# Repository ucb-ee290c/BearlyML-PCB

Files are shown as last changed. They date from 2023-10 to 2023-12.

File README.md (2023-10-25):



# BearlyML-PCB

This is the PCB for BearlyML 22 SoC chip, designed by EE 194/290C students in Spring 2022. 

## Functional Description

The design consists of two boards. The Module Board breaks out the chip BGA signals to the SODIMM connector. The Carrier Board contains most of the IO modules and level shifters. The Carrier Board can be swapped to different designs for different bringup setups or demo applications.

## Project Links

[BearlyML 2022 SoC Specification](https://docs.google.com/document/d/1Ldz2ZDB1uXTN-R59TmTNYh7_aXbSfiJJrKeP0uHo0qY/edit?usp=sharing)

[BearlyML 2022 Testing Note](https://docs.google.com/presentation/d/11BuBN2AjHtR5hc7lh9h7Z0UspvnxgiJxumvH6YZSuuI/edit?usp=sharing)

[PCB Design Review Slides](https://docs.google.com/presentation/d/1bnDwFzTTJ-bXILV92_7TXTGvEWACcQbSM0IduBUi0zo/edit?usp=sharing)

[PCB Project on GitHub](https://github.com/ucb-ee290c/BearlyML-PCB)

[PCB Project on Altium 365 - Module](https://ucb-bar.365.altium.com/designs/3D97ECBB-57EB-4ED6-8AAA-B185523FADBC#design)

[PCB Project on Altium 365 - Carrier](https://ucb-bar.365.altium.com/designs/955C9C27-6A6A-45D4-90F7-2286846251A1#design)

[PCB Project in BWRC-Boards](https://bwrcrepo.eecs.berkeley.edu/pcb/BearlyML-PCB)

## Schematic

[View on Altium 365](https://ucb-bar.365.altium.com/designs/3D97ECBB-57EB-4ED6-8AAA-B185523FADBC#design)

[Schematic PDF - Module](BearlyML_Module_Board/schematic-pdf/Schematic_BearlyML%20Module%20Board_2022-12-21.pdf)

[Schematic PDF - Carrier](BearlyML_Carrier_Board/schematic-pdf/Schematic_BearlyML%20Carrier%20Board_2022-12-21.pdf)

### Manufacture

[JLCPCB](https://jlcpcb.com/capabilities/Capabilities)

### Parameters

| Key | Value |
| ---- | --- |
| Build Time | 5-6 days |
| Layers | 6  |
| PCB Qty | 5 |
| PCB Thickness | 1.2 mm for Module Board; 1.6 mm for Carrier Board |
| Base Material | FR-4 |
| Material Type | FR4-Standard TG 135-140 |
| Dimension | 79.6 mm* 71 mm for Module Board; 100 mm* 92 mm for Carrier Board |
| Product Type | Industrial/Consumer electronics |
| Impedance Control | no |
| Silkscreen | White |
| PCB Color | Black |
| Surface Finish | ENIG Gold Thickness: 1 U" |
| Via Covering | Epoxy Filled & Capped |
| Via Type | via-in-pad |
| Outer Copper Weight | 1 oz |
| Inner Copper Weight | 0.5 oz |
| Castellated Holes | no |
| Min hole size/diameter | 0.2/0.45mm |
| Flying Probe Test | Fully Test |
| Gold Fingers | Yes for Module Board |
| Remove Order Number | Specify a location |
| Appearance Quality | IPC Class 2 Standard |
| Silkscreen Technology | Ink-jet/Screen Printing Silkscreen |



Manufactured with [JLCPCB](https://jlcpcb.com/).

## Manufacture Cost

### Module Board

PCB: $18.58 each

Assembly: $17.64 each excluding BOM part cost

### Carrier Board

PCB: $17.81 each

Assembly: $21.90 each excluding BOM part cost

### Total

Total: $380 for 5 pcs

## 3D View

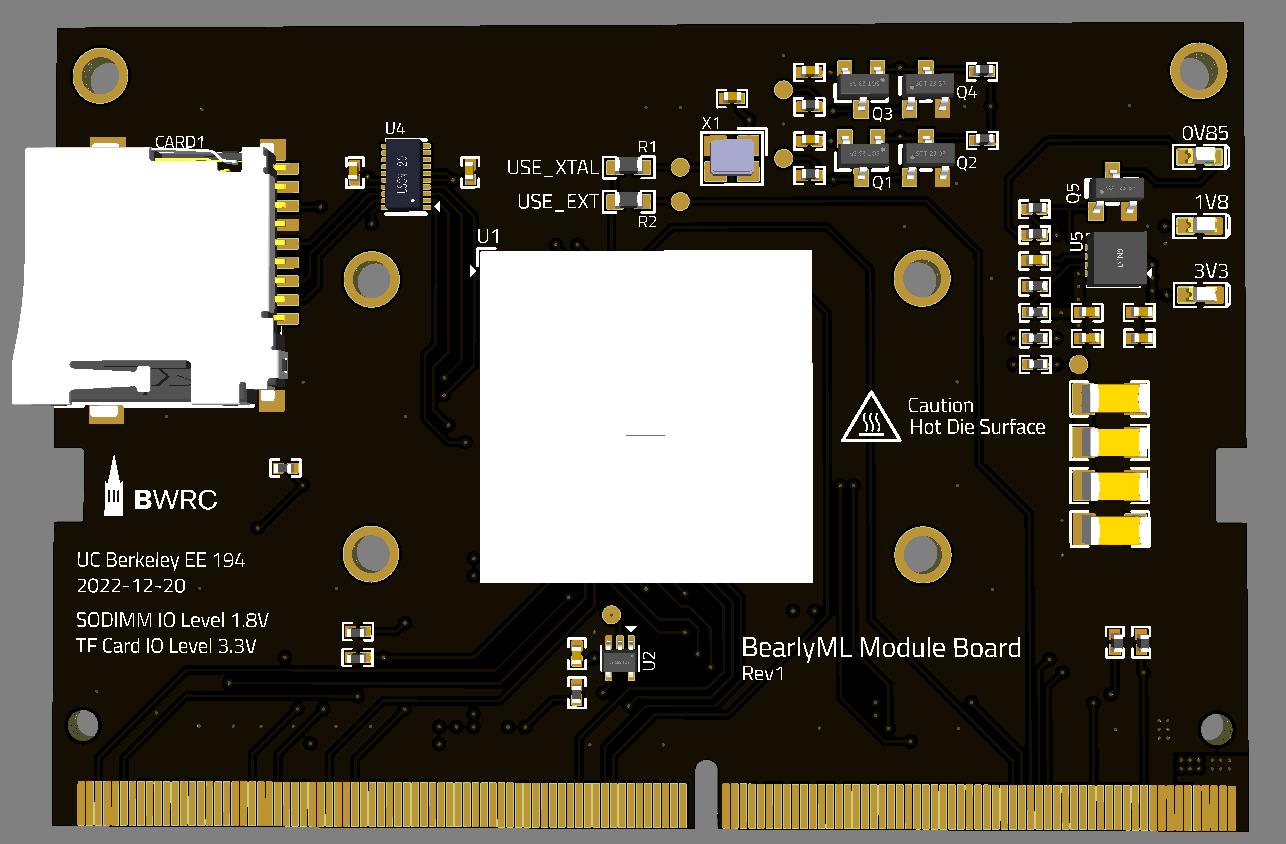
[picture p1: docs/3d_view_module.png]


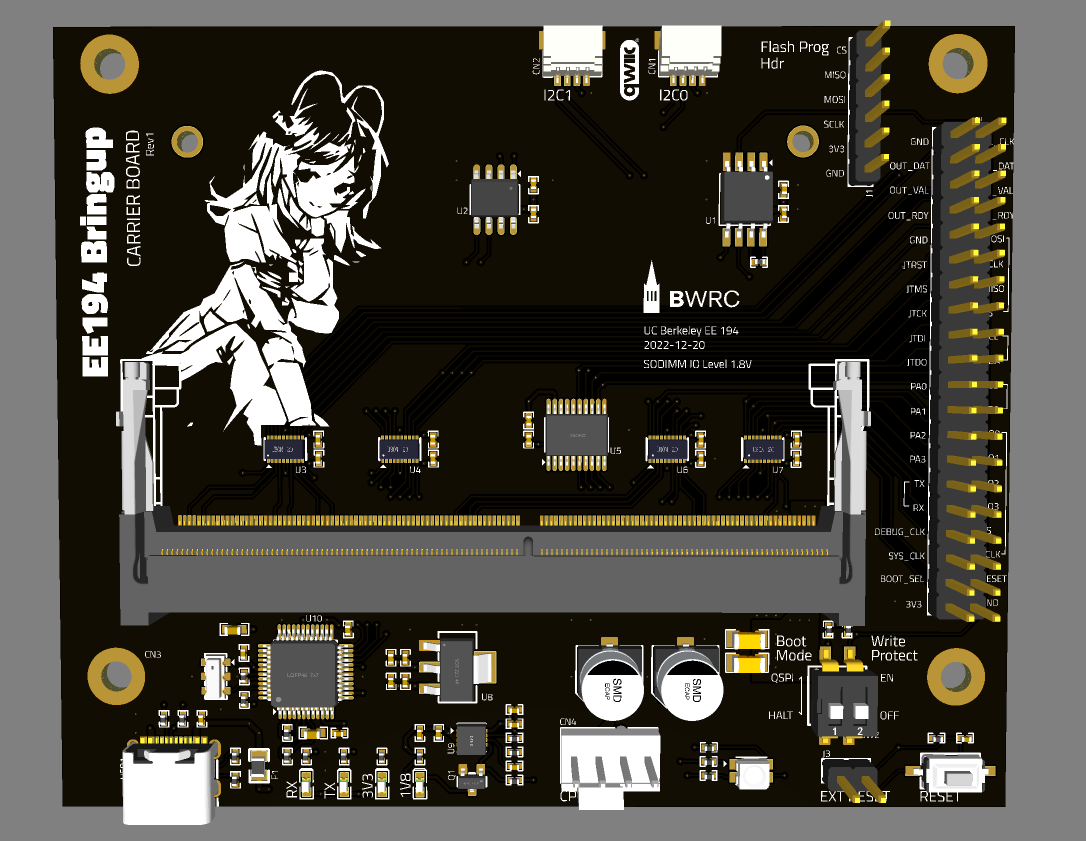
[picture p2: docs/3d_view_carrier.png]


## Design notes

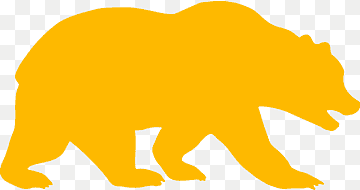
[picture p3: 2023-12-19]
assets/bearlyml_bear.png

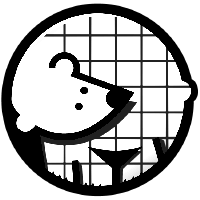
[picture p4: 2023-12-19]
assets/ucb-bar.png

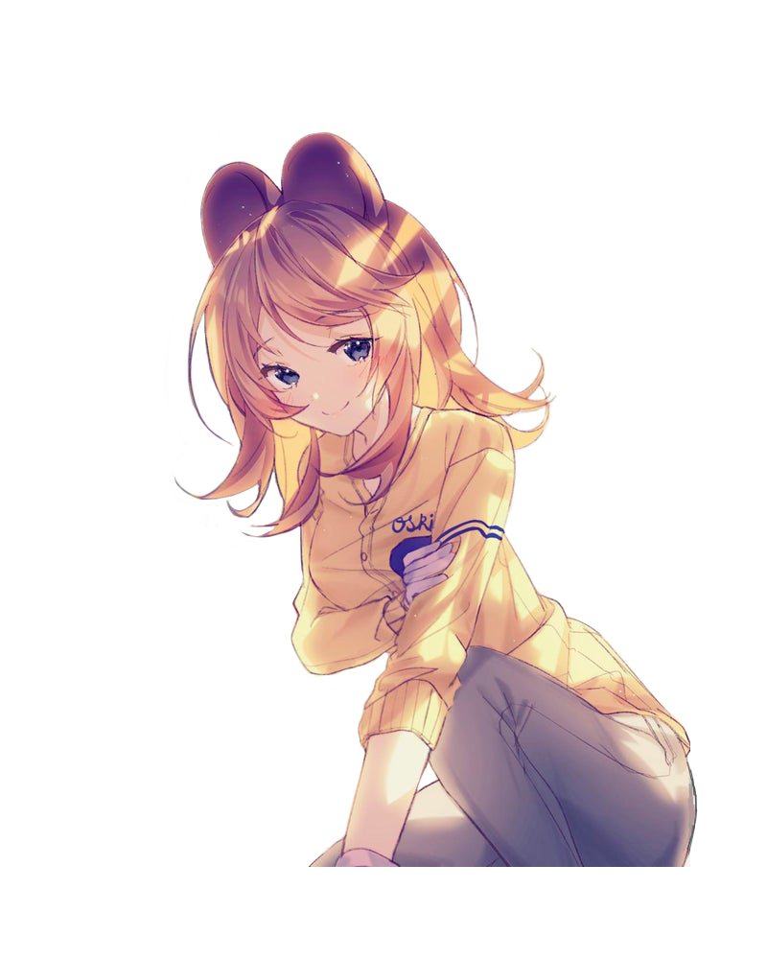
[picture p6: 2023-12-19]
assets/bearlyml_raw.jpg

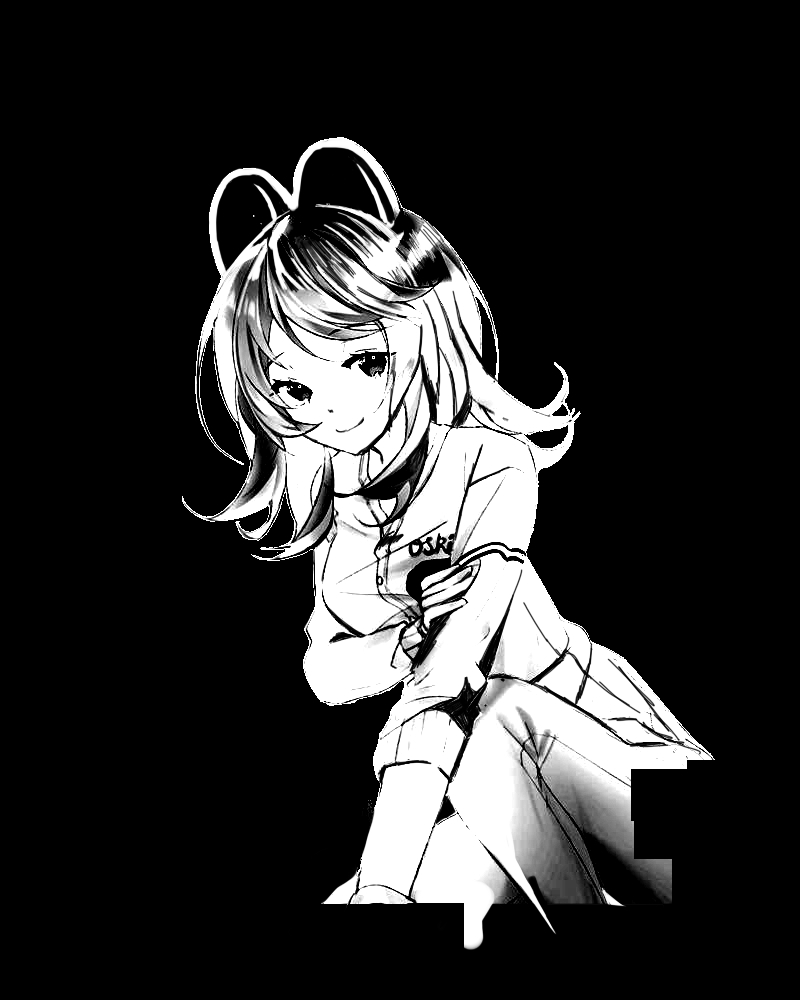
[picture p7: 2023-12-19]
assets/bearlyml.jpg

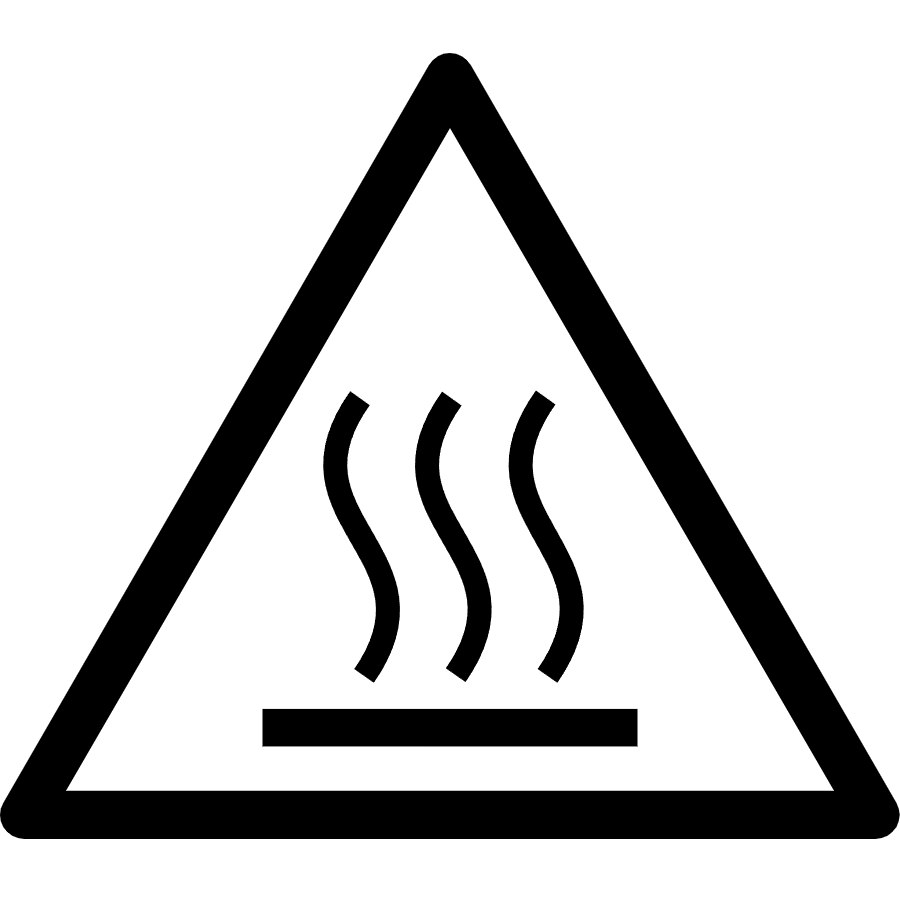
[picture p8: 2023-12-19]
assets/hot.png

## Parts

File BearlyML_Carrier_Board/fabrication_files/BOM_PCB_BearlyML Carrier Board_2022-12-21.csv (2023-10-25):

ID | Name | Designator | Footprint | Quantity | Manufacturer Part | Manufacturer | Supplier | Supplier Part | Price
1 | ASAA826-E8SB0-7H | CN3 | CONN-SMD_ASAA826-E8SB0-7H | 1 | ASAA826-E8SB0-7H | FOXCONN(富士康) | LCSC | C2761395 | 8.05
2 | USB-TYPEC | USB1 | USB-C-SMD_KH-TYPE-C-16P | 1 | KH-TYPE-C-16P | Shenzhen Kinghelm Elec | LCSC | C709357 | 0.5111
3 | KF1027B-02P-L00-ON-01B | SW2 | SW-SMD_4P-L6.1-W6.2-P2.54-LS10.0 | 1 | KF1027B-02P-L00-ON-01B | 凯峰 | LCSC | C976353 | 1.8078
4 | TS-1007S-AR02516 | SW1 | SW-SMD_L6.1-W3.6-LS7.9 | 1 | TS-1007S-AR02516 | XUNPU | LCSC | C720381 | 0.2704
5 | 27R | R7,R9 | RES-0402 | 2 | RCT0227RJLF | HKR | LCSC | C174257 | 0.0093
6 | FDV301N | Q1 | SOT-23_L2.9-W1.3-P1.90-LS2.4-BR | 1 | FDV301N | onsemi(安森美) | LCSC | C15310 | 0.383
7 | 6V 2A | F1 | R0805 | 1 | SL0805200 | TECHFUSE | LCSC | C70158 | 0.3669
8 | AMS1117-3.3 | U8 | SOT-223_L6.5_W3.5_P2.30_BL | 1 | AMS1117-3.3 | Advanced Monolithic Systems | LCSC | C6186 | 0.9139
9 | 1k5 | R27 | RES-0402 | 1 | 0402WGF1501TCE | UniOhm 台湾厚声 | LCSC | C25867 | 0.0026
10 | 10k | R26,R23,R4,R3,R2,R1 | RES-0402 | 6 | 0402WGF1002TCE | UniOhm 台湾厚声 | LCSC | C25744 | 0.0036
11 | 470R | R25 | RES-0402 | 1 | 0402WGF4700TCE | UniOhm 台湾厚声 | LCSC | C25117 | 0.0029
12 | 1M | R24 | RES-0402 | 1 | 0402WGF1004TCE | UniOhm 台湾厚声 | LCSC | C26083 | 0.0027
13 | 1k | R22,R19,R18,R17,R10,R8,R6 | RES-0402 | 7 | 0402WGF1001TCE | UniOhm 台湾厚声 | LCSC | C11702 | 0.0028
14 | 47k | R21 | RES-0402 | 1 | 0402WGF4702TCE | UniOhm 台湾厚声 | LCSC | C25792 | 0.0029
15 | 160k | R20 | RES-0402 | 1 | 0402WGF1603TCE | UniOhm 台湾厚声 | LCSC | C25757 | 0.003
16 | 5k1 | R11,R5 | RES-0402 | 2 | 0402WGF5101TCE | UniOhm 台湾厚声 | LCSC | C25905 | 0.003
17 | LED-0603_B | LED5 | LED-0603 | 1 | XL-0603QBC | KENTO | LCSC | C2288 | 0.0551
18 | LED-0603_W | LED4,LED3 | LED-0603 | 2 | LED White | KENTO | LCSC | C2290 | 0.0717
19 | LED-0603_R | LED2 | LED-0603 | 1 | 19-217/R6C-AL1M2VY/3T | EVERLIGHT 台湾亿光 | LCSC | C72044 | 0.1065
20 | HDR-M-2.54_1x2 | J3 | HDR-M-2.54_1X2 | 1 |  |  | LCSC | C124375 | 0.1388
21 | HDR-M-2.54_2x20 | J2 | HDR-M-2.54_2X20 | 1 |  |  | LCSC | C50980 | 0.8242
22 | HDR-M-2.54_1x6 | J1 | HDR-M-2.54_1X6 | 1 |  |  | LCSC | C190819 | 0.1949
23 | 47053-1000 | CN4 | CONN-TH_47053-1000 | 1 | 470531000 | MOLEX | LCSC | C240840 | 1.0789
24 | SM04B-SRSS-TB(LF)(SN) | CN2,CN1 | CONN-SMD_4P-P1.00_SM04B-SRSS-TB-LF-SN | 2 | SM04B-SRSS-TB(LF)(SN) | JST | LCSC | C160404 | 1.1023
25 | 33n | C34 | CAPA-0603 | 1 | CL10B333KB8NNNC | SAMSUNG | LCSC | C21117 | 0.0297
26 | 100n | C33,C32,C31,C27,C26,C24,C21,C16,C15,C14,C13,C12,C11,C10,C9,C8,C7,C4,C3,C1 | CAPA-0402 | 20 | CL05B104KB54PNC | SAMSUNG | LCSC | C307331 | 0.0399
27 | 10u | C30 | CAPA-0603 | 1 | CL10A106KP8NNNC | SAMSUNG | LCSC | C19702 | 0.0406
28 | 1n | C29 | CAPA-0402 | 1 | CC0402JRNPO9BN102 | YAGEO 国巨 | LCSC | C113780 | 0.0295
29 | 10u | C28,C25,C23,C22 | CAPA-0402 | 4 | JMK105CBJ106MV-F | TAIYO YUDEN | LCSC | C87148 | 0.0679
30 | 22u | C20,C19 | CAPA-1206 | 2 | CL31A226KAHNNNE | SAMSUNG | LCSC | C12891 | 0.3256
31 | 220u | C18,C17 | CAPPR5.0-D6.3_L6.6_W6.6 | 2 | CK1A221M-CRE54 | SEMTECH 先科 | LCSC | C131157 | 0.2157
32 | 10n | C6 | CAPA-0402 | 1 | CL05B103KB5NNNC | SAMSUNG | LCSC | C15195 | 0.0058
33 | 1u | C5,C2 | CAPA-0402 | 2 | CL05A105KA5NQNC | SAMSUNG | LCSC | C52923 | 0.0198
34 | FT2232D | U10 | LQFP-48_L7.0-W7.0-P0.50-LS9.0-BL | 1 | FT2232D | FTDI | LCSC | C428116 | 143.5
35 | TXS0108EPWR | U5 | TSSOP-20_L6.5-W4.4-P0.65-LS6.4-BL | 1 | TXS0108EPWR | TI | LCSC | C17206 | 3.93
36 | LED-RGB | LED1 | LED-ARRAY-SMD_4P-L3.2-W2.7-TL-RD_TJ-S3528 | 1 | TJ-S3528UG2W9TLCCYRGB-A5 | TOGIALED | LCSC | C601699 | 0.5746
37 | MCP1726-ADJE/MF | U9 | DFN-8_L3.0-W3.0-P0.50-LS3.0-BL-EP | 1 | MCP1726-ADJE/MF | MICROCHIP(美国微芯) | LCSC | C184287 | 10.34
38 | 6MHz | X1 | CRYSTAL-SMD_3P-L4.5-W2.0-L | 1 | CSTCR6M00G53-R0 | muRata(村田) | LCSC | C85845 | 1.6686
39 | TXB0108DQSR | U7,U6,U4,U3 | SON-20_L4.0-W2.0-P0.40-BL | 4 | TXB0108DQSR | TI | LCSC | C427057 | 7.01
40 | IS25LP032D-JBLA3 | U1 | SOIC-8_L5.3-W5.3-P1.27-LS7.9-BL | 1 | IS25LP032D-JBLA3 | ISSI(美国芯成) | LCSC | C1236833 | 10.57

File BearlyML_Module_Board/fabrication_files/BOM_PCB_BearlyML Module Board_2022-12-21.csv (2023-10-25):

ID | Name | Designator | Footprint | Quantity | Manufacturer Part | Manufacturer | Supplier | Supplier Part | Price
1 | 100n | C3,C4,C5,C7,C8,C9,C1,C2,C6,C13,C14,C15,C17,C18 | CAPA-0402 | 14 | CL05B104KB54PNC | SAMSUNG | LCSC | C307331 | 0.0399
2 | 1u | C10,C11,C12 | CAPA-0402 | 3 | CL05A105KA5NQNC | SAMSUNG | LCSC | C52923 | 0.0198
3 | AO3401A | Q1,Q3 | SOT-23_L2.9-W1.3-P1.90-LS2.4-BR | 2 | AO3401A | AOS | LCSC | C15127 | 0.5604
4 | TXB0108DQSR | U4 | SON-20_L4.0-W2.0-P0.40-BL | 1 | TXB0108DQSR | TI | LCSC | C427057 | 7.01
5 | AO3400A | Q2,Q4 | SOT-23_L2.9-W1.3-P1.90-LS2.4-BR | 2 | AO3400A | AOS | LCSC | C20917 | 0.6785
6 | BearlyML | U1 | FC-PBGA-1.0-324-R18-C18_INTEL | 1
7 | MCP1726-ADJE/MF | U5 | DFN-8_L3.0-W3.0-P0.50-LS3.0-BL-EP | 1 | MCP1726-ADJE/MF | MICROCHIP(美国微芯) | LCSC | C184287 | 10.34
8 | SN74LVC1G04DCKR | U2 | SOT-353_L2.1-W1.3-P0.65-LS2.3-BR | 1 | SN74LVC1G04DCKR | TI | LCSC | C8207 | 0.4538
9 | 10u | C16,C19 | CAPA-0402 | 2 | JMK105CBJ106MV-F | TAIYO YUDEN | LCSC | C87148 | 0.0679
10 | 1n | C20 | CAPA-0402 | 1 | CC0402JRNPO9BN102 | YAGEO 国巨 | LCSC | C113780 | 0.0295
11 | 22u | C21,C22 | CAPA-1206 | 2 | CL31A226KAHNNNE | SAMSUNG | LCSC | C12891 | 0.3256
12 | 2u2 | C23,C24 | CAPA-1206 | 2 | CL31B225KBHNNNE | SAMSUNG | LCSC | C50254 | 0.1073
13 | 20MHz | X1 | OSC-SMD_4P-L2.5-W2.0-BL | 1 | OT252020MJBA4SL | YXC 扬兴晶振 | LCSC | C669067 | 3.88
14 | TF-01A | CARD1 | TF-SMD_TF-01A | 1 | TF-01A | 韩国韩荣 | LCSC | C91145 | 1.097
15 | LED-0603_B | LED1,LED2,LED3 | LED-0603 | 3 | XL-0603QBC | KENTO | LCSC | C2288 | 0.0551
16 | FDV301N | Q5 | SOT-23_L2.9-W1.3-P1.90-LS2.4-BR | 1 | FDV301N | onsemi(安森美) | LCSC | C15310 | 0.383
17 | 1k | R3,R4,R5,R6,R14,R15,R18 | RES-0402 | 7 | 0402WGF1001TCE | UniOhm 台湾厚声 | LCSC | C11702 | 0.0028
18 | 100k | R7,R8,R9,R10,R11,R12 | RES-0402 | 6 | 0402WGF1003TCE | UniOhm 台湾厚声 | LCSC | C25741 | 0.0029
19 | 130k | R16 | RES-0402 | 1 | 0402WGF1303TCE | UniOhm 台湾厚声 | LCSC | C52929 | 0.0032
20 | 120k | R17 | RES-0402 | 1 | 0402WGF1203TCE | UniOhm 台湾厚声 | LCSC | C25750 | 0.0029
21 | 10k | R19 | RES-0402 | 1 | 0402WGF1002TCE | UniOhm 台湾厚声 | LCSC | C25744 | 0.0036
22 | 0R | R1 | RES-0603 | 1 | 0603WAF0000T5E | UniOhm 台湾厚声 | LCSC | C21189 | 0.0057

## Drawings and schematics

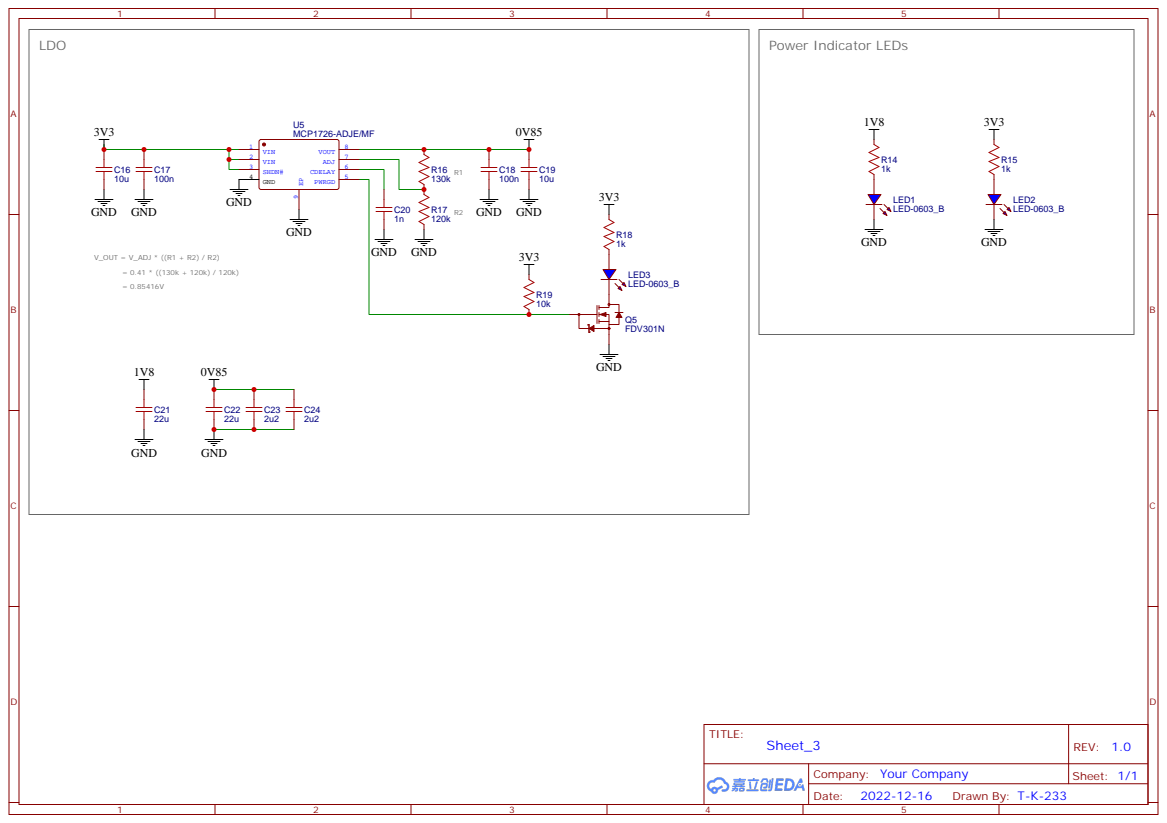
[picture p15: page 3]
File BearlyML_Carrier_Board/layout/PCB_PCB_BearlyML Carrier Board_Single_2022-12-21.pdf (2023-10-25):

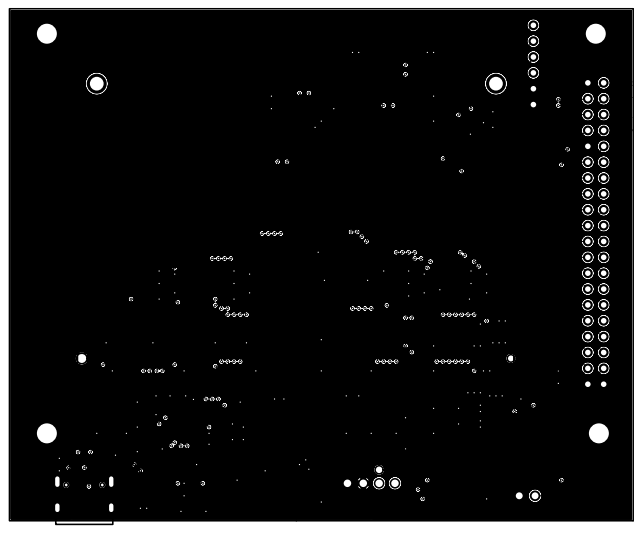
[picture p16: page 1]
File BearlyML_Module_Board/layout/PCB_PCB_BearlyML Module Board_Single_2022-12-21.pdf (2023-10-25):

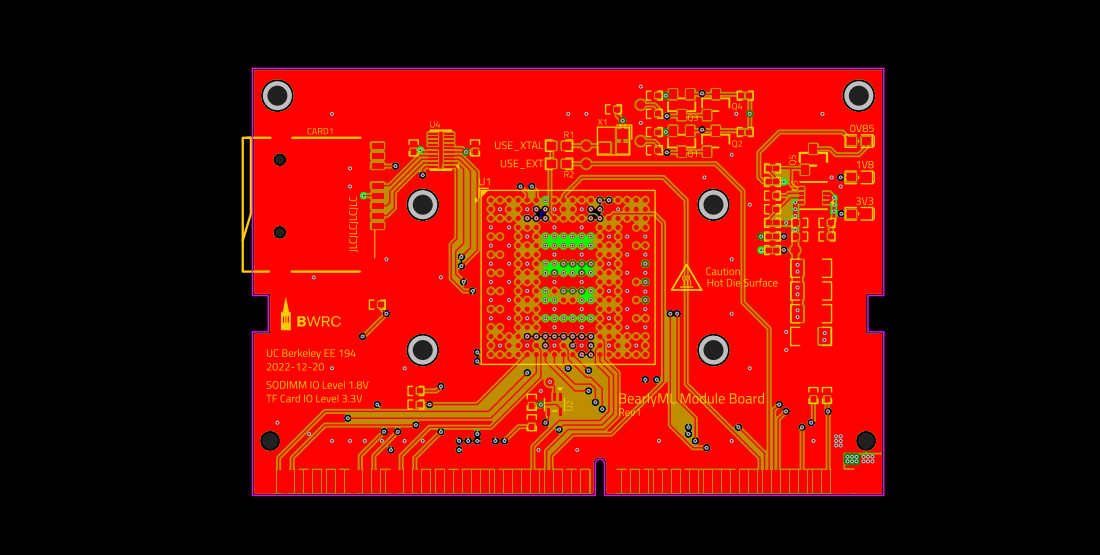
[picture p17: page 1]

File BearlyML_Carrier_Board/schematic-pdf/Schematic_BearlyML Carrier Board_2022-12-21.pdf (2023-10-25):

## GND

## GND

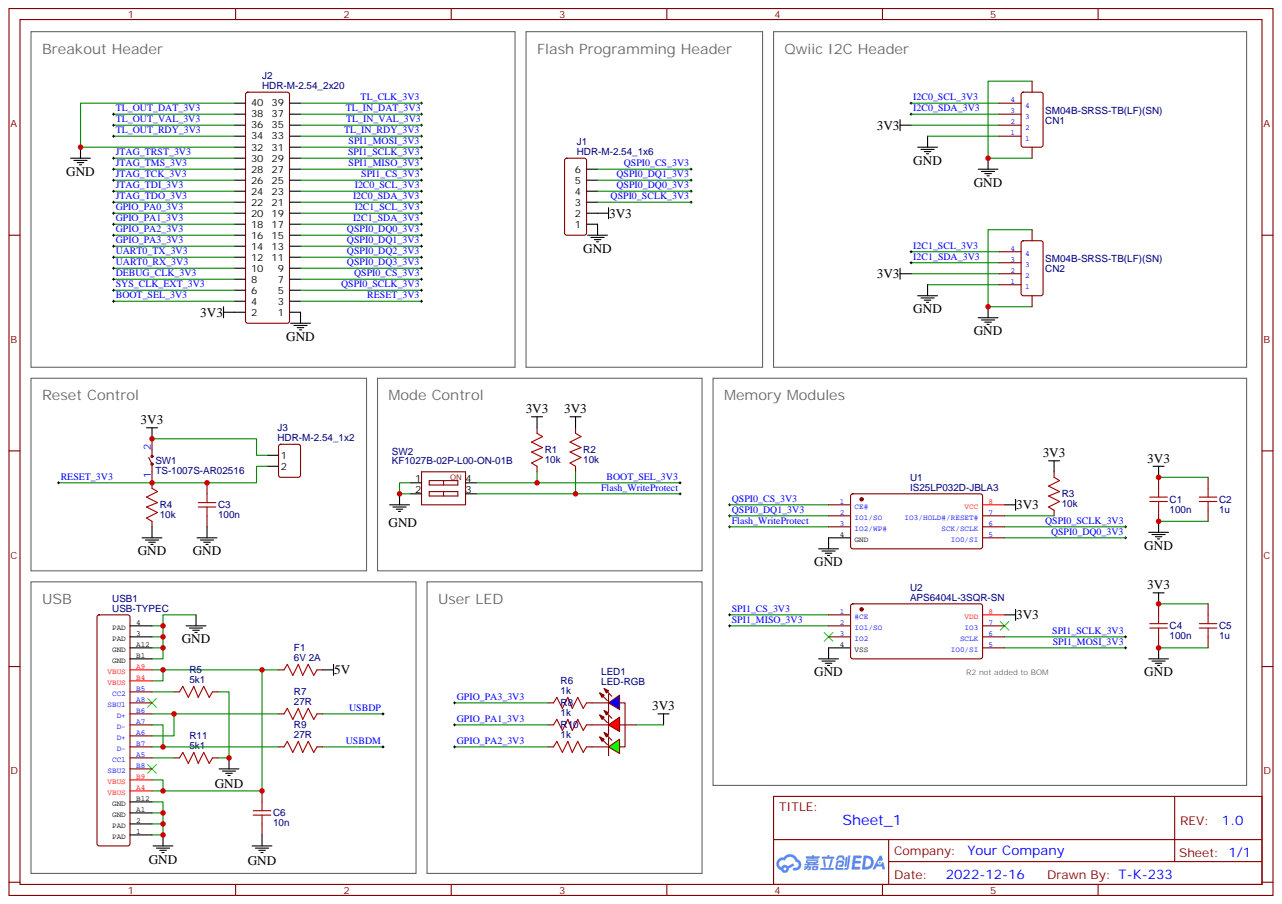
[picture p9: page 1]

R2 not added to BOM

## GND

1V8 | 3V3

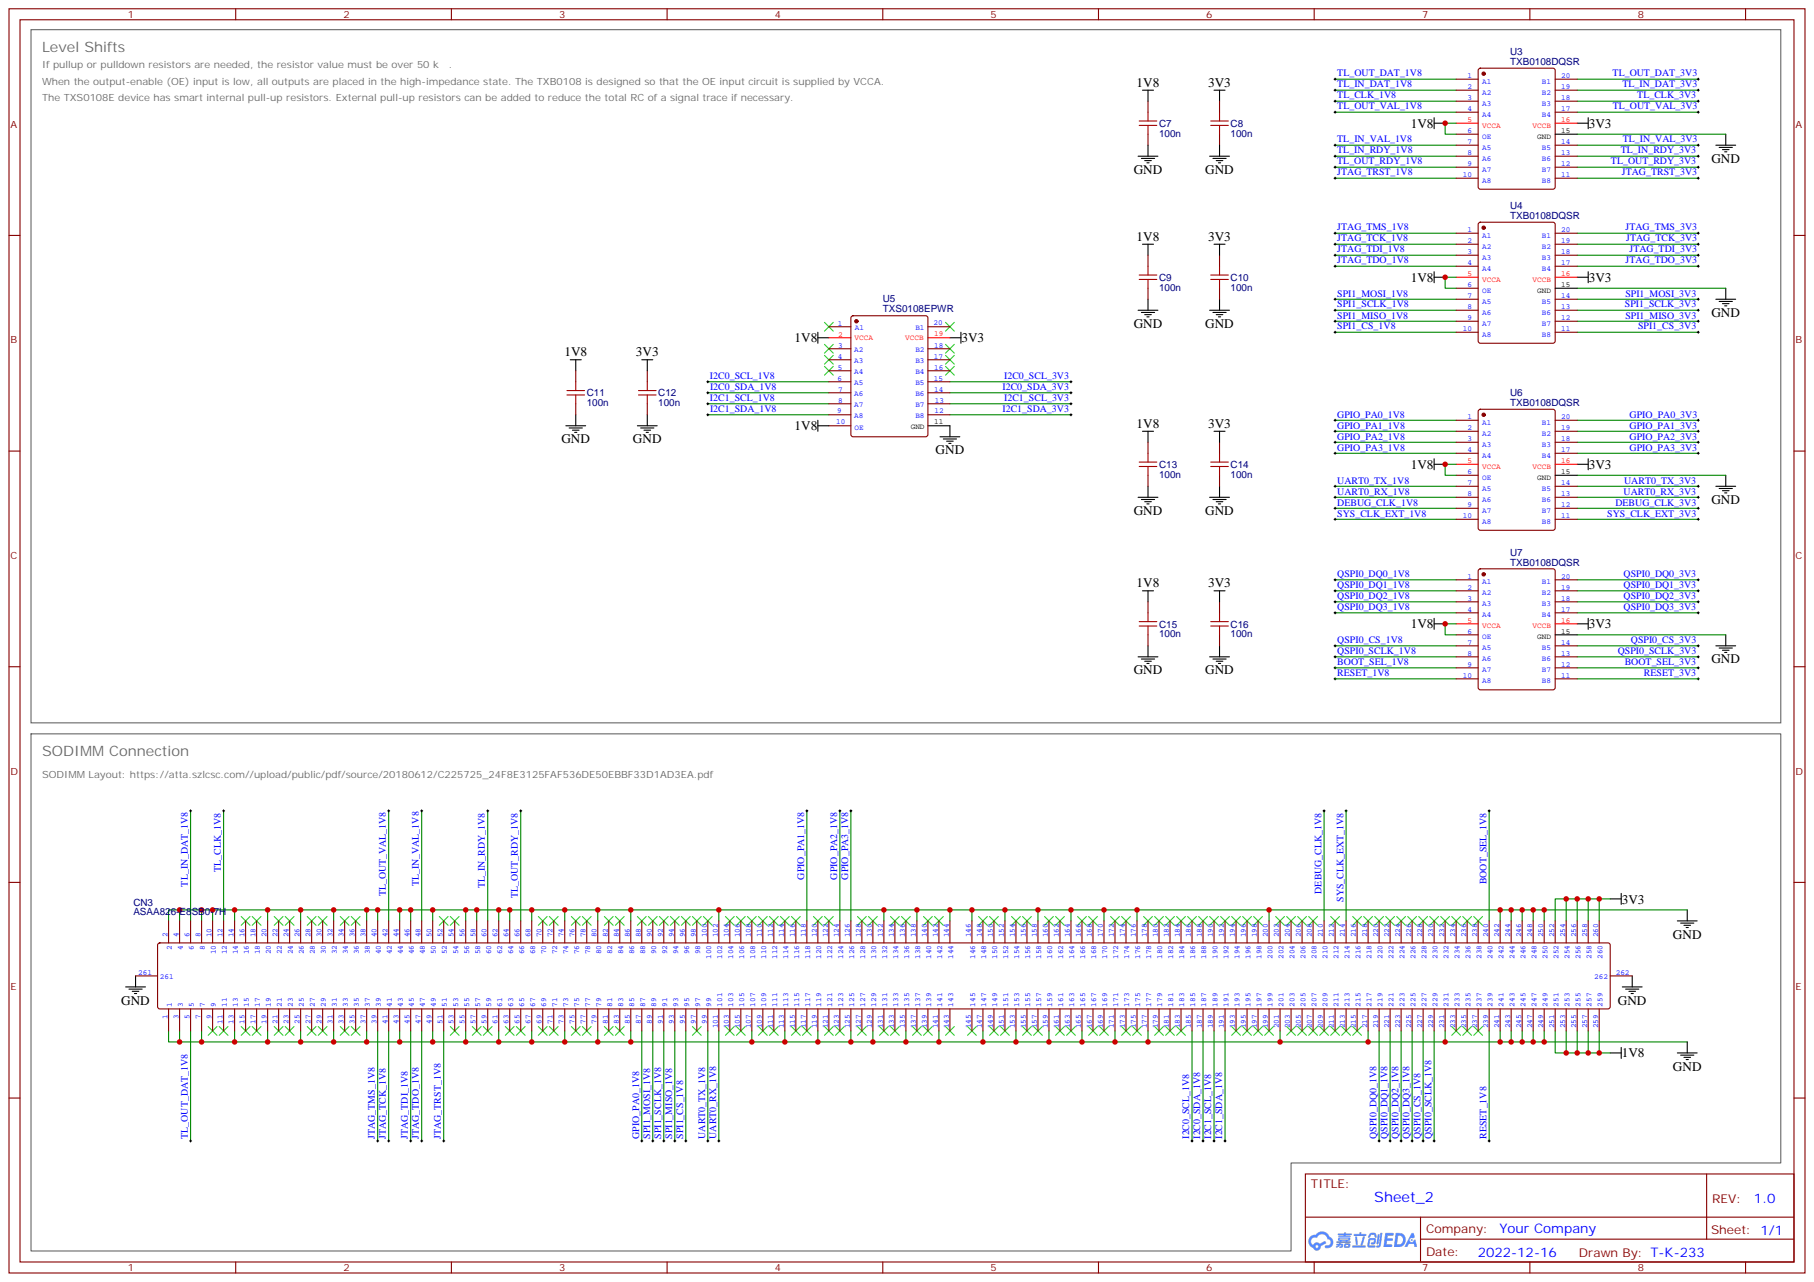
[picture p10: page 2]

Level Shifts
If pullup or pulldown resistors are needed, the resistor value must be over 50 k .
When the output-enable (OE) input is low, all outputs are placed in the high-impedance state. The TXB0108 is designed so that the OE input circuit is supplied by VCCA.
The TXS0108E device has smart internal pull-up resistors. External pull-up resistors can be added to reduce the total RC of a signal trace if necessary.

SODIMM Layout: https://atta.szlcsc.com//upload/public/pdf/source/20180612/C225725_24F8E3125FAF536DE50EBBF33D1AD3EA.pdf

5V

GND | 3V3

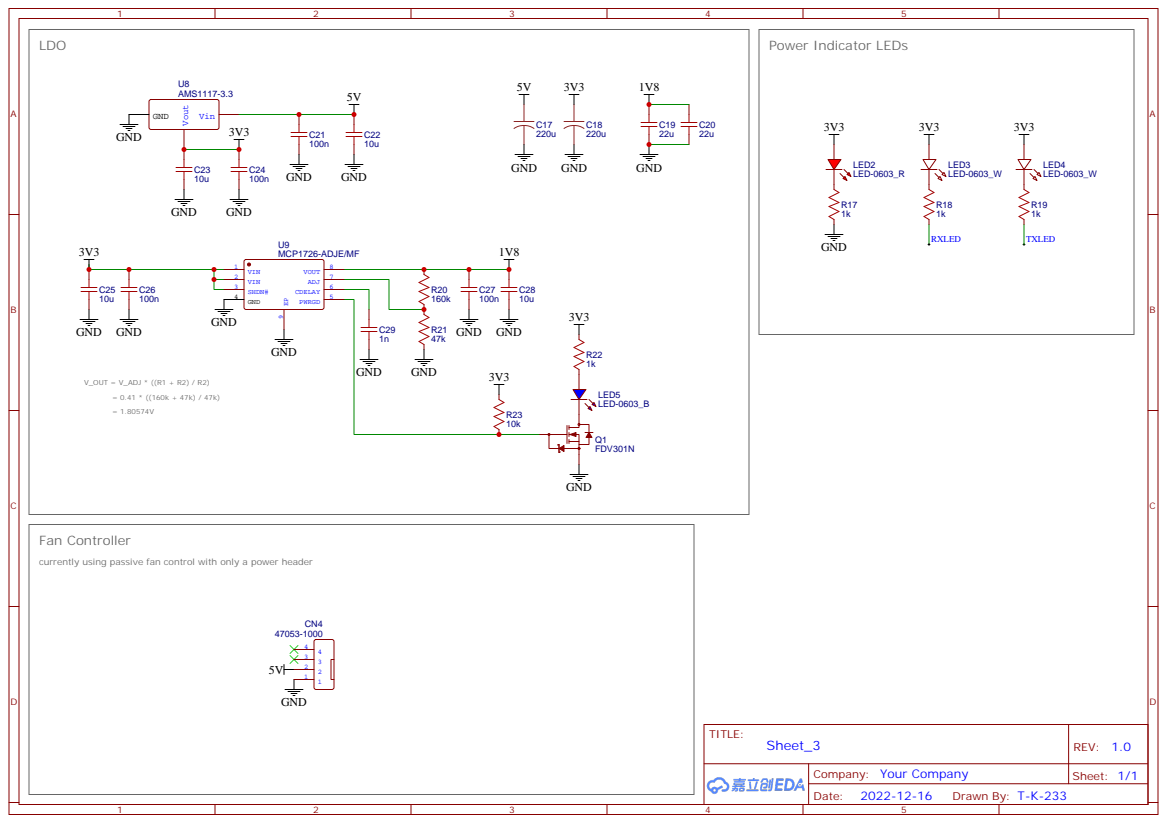
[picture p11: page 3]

currently using passive fan control with only a power header

3V3

## GND

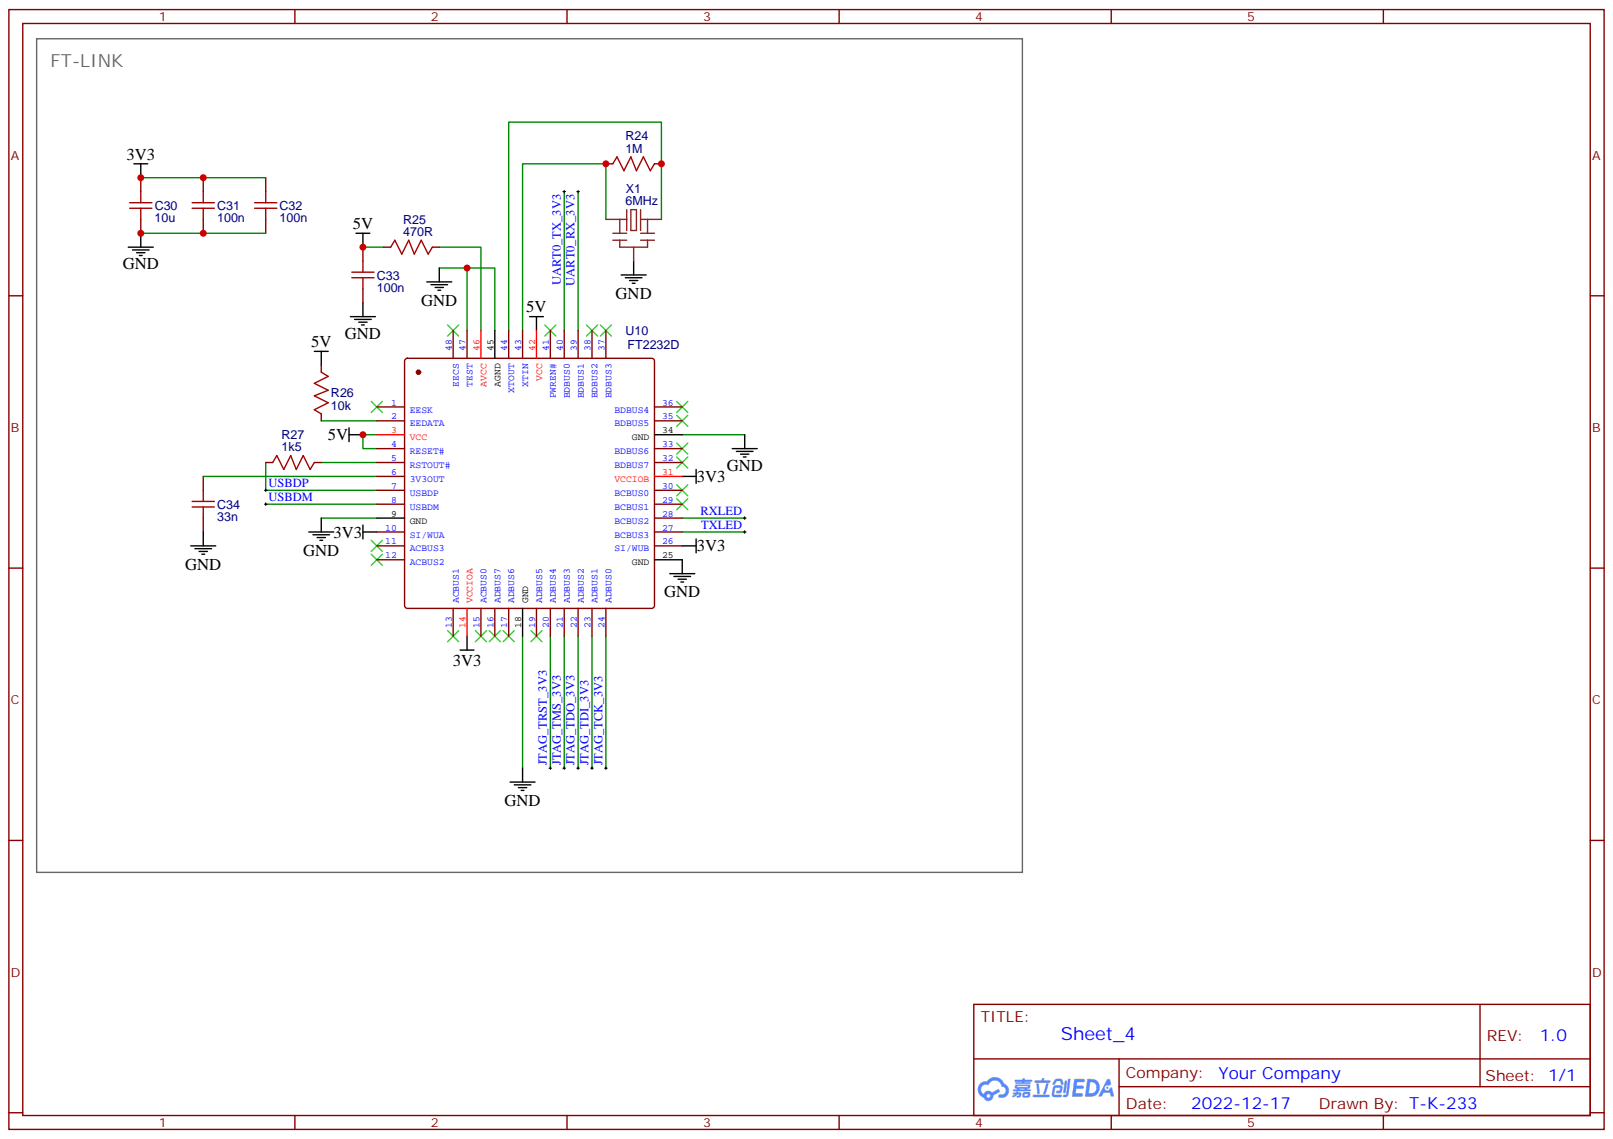
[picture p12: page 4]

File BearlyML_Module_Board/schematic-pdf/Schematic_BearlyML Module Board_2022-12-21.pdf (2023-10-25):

A

A

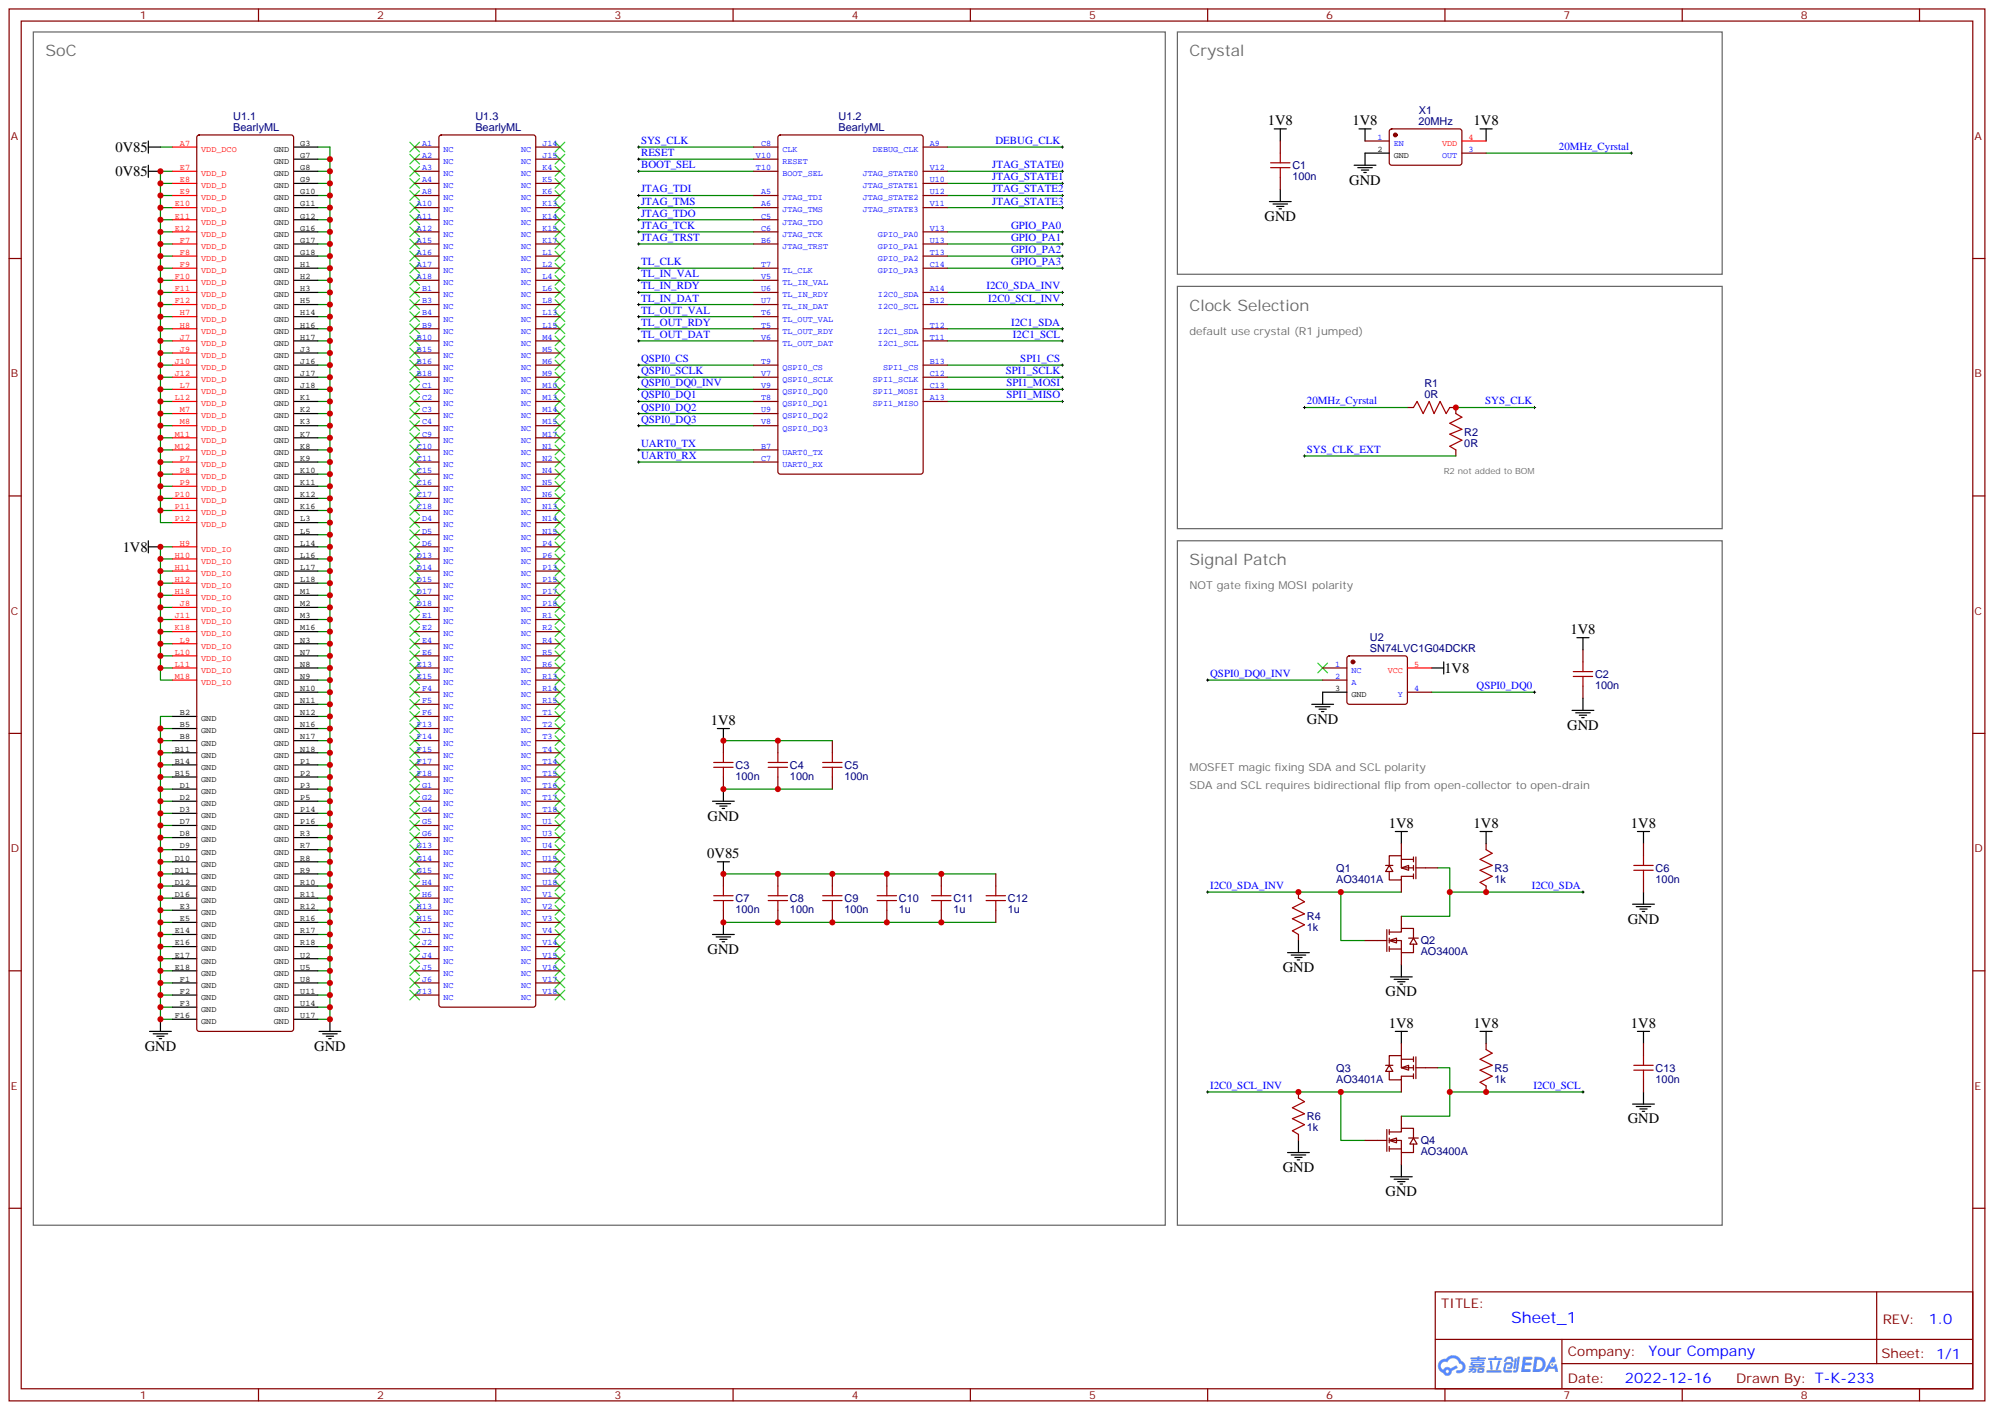
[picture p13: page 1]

default use crystal (R1 jumped)

R2 not added to BOM

NOT gate fixing MOSI polarity

MOSFET magic fixing SDA and SCL polarity
SDA and SCL requires bidirectional flip from open-collector to open-drain

A | A

1

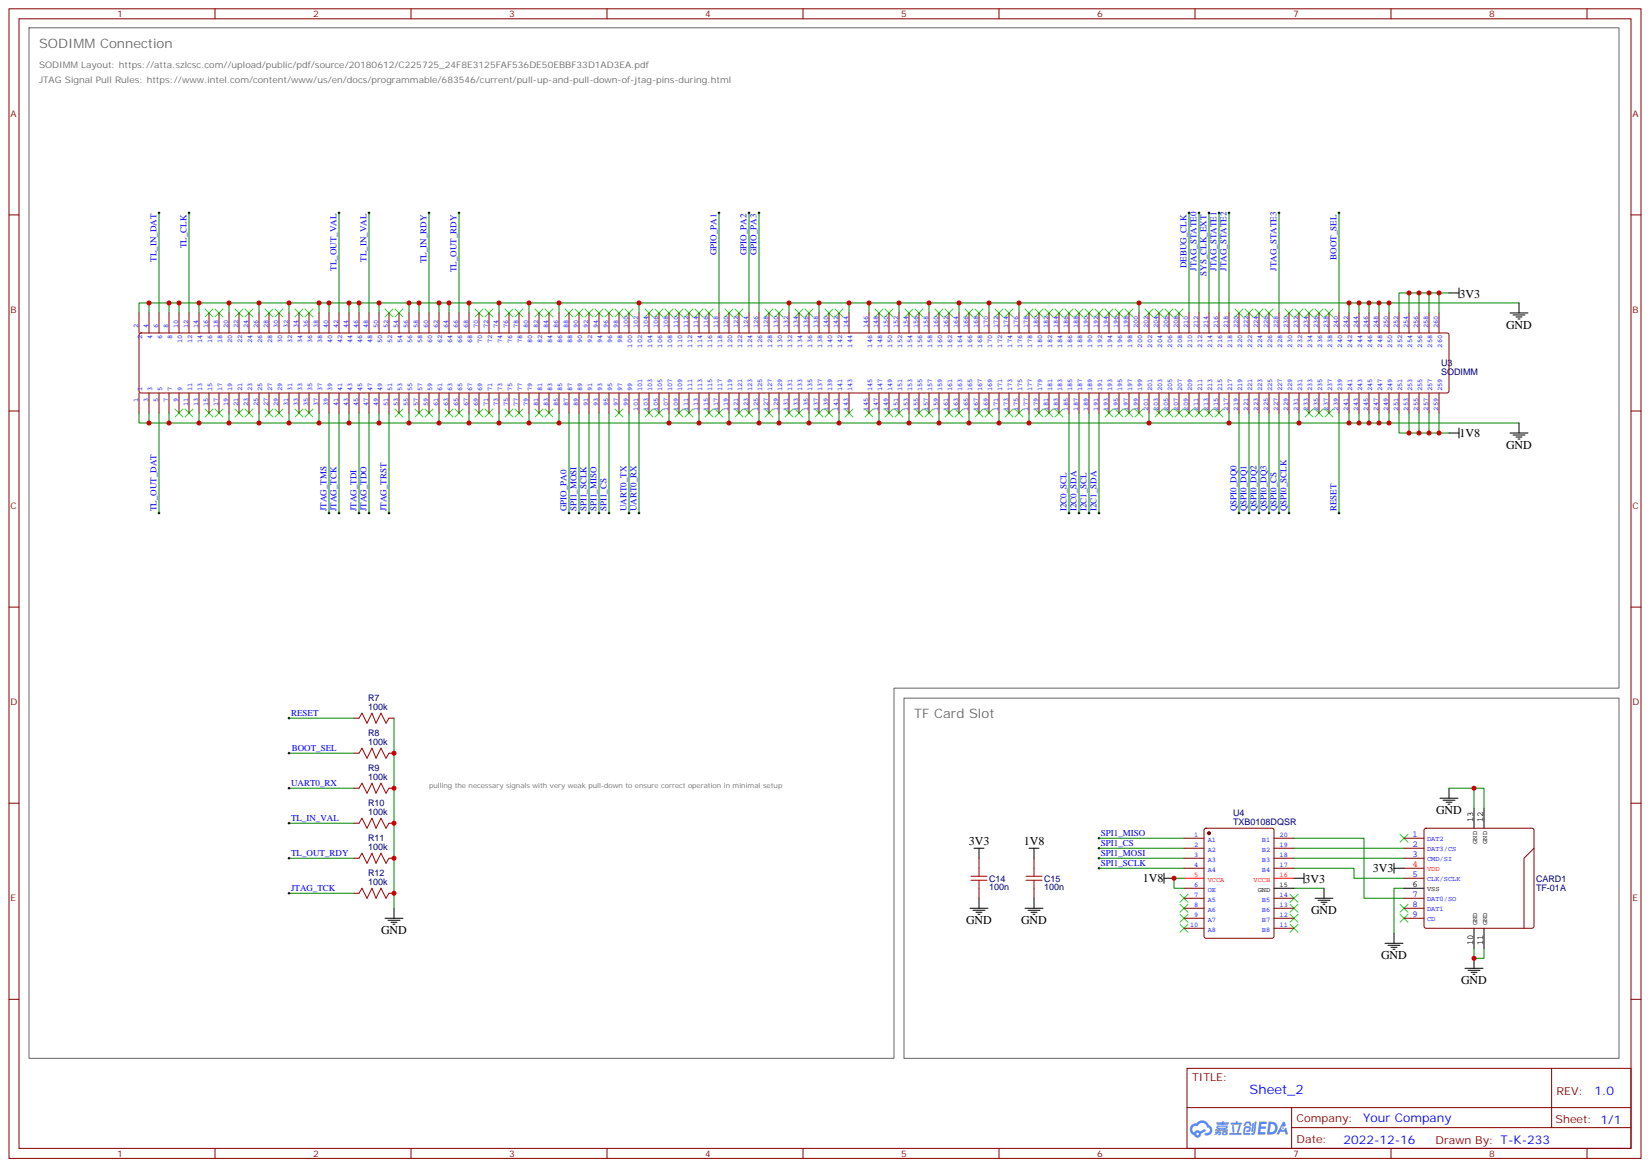
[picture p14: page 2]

SODIMM Layout: https://atta.szlcsc.com//upload/public/pdf/source/20180612/C225725_24F8E3125FAF536DE50EBBF33D1AD3EA.pdf
JTAG Signal Pull Rules: https://www.intel.com/content/www/us/en/docs/programmable/683546/current/pull-up-and-pull-down-of-jtag-pins-during.html

pulling the necessary signals with very weak pull-down to ensure correct operation in minimal setup

A | A

1
